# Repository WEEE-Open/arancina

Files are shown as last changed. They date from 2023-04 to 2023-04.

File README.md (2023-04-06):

# Arancina
The **Arancina** (**A**utonomous **R**AM **AN**alysis **CI**rcuit for **N**ot-broken **A**rrays) is a FPGA-based tool for testing the functionality of a DDR RAM, checking its characteristics and operating status through a series of test procedures.

The first prototype is built upon a Terasic [DE0-Nano](https://www.terasic.com.tw/cgi-bin/page/archive.pl?No=593) board, connected to an external DDR memory chip through a custom shield ([DDRacula](pcb/ddracula)), and using an LCD display and a bunch of buttons as user interface.

The tool is still **under heavy development** and not ready for use.

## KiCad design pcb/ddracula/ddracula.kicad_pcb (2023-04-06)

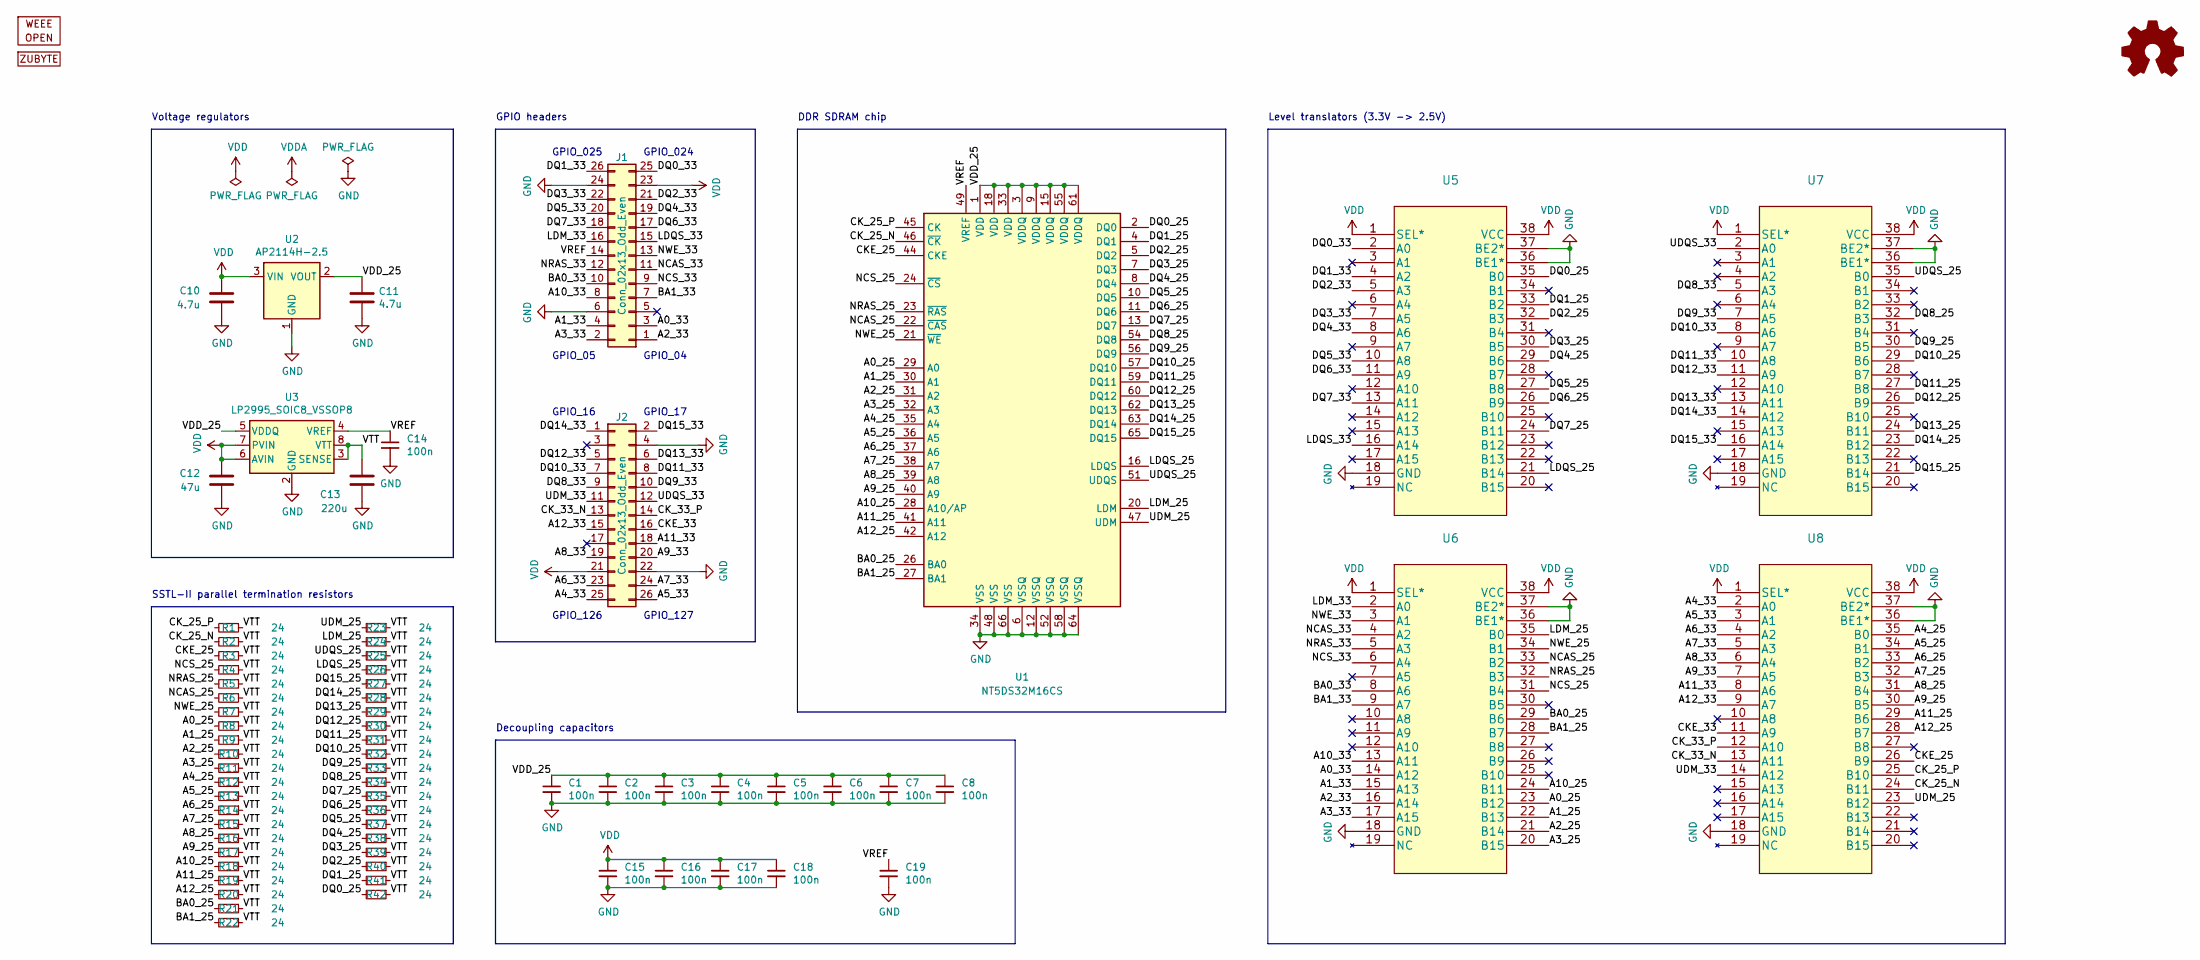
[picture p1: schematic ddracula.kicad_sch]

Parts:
C1, C2, C3, C4, C5, C6, C7, C8, C14, C15, C16, C17, C18, C19: 100n; C_0402_1005Metric
C10, C11: 4.7u; C_0805_2012Metric
C12: 47u; C_0805_2012Metric
C13: 220u; C_1206_3216Metric
J1, J2: Conn_02x13_Odd_Even; PinSocket_2x13_P2.54mm_Vertical
LOGO1: WEEE_Open; Logo_WO_First_Letter
LOGO2: Zubyte; Logo_Zubyte
LOGO3: Logo_Open_Hardware_Small; OSHW-Logo_5.7x6mm_SilkScreen
R1, R2, R3, R4, R5, R6, R7, R8, R9, R10, R11, R12, R13, R14, R15, R16, R17, R18, R19, R20, R21, R22, R23, R24, R25, R26, R27, R28, R29, R30, R31, R32, R33, R34, R35, R36, R37, R38, R39, R40, R41, R42: 24; R_0402_1005Metric
U1: NT5DS32M16CS; TSOP-II-66_22.2x10.16mm_P0.8mm
U2: AP2114H-2.5; SOT-223
U3: LP2995_SOIC8_VSSOP8; SOIC-8_3.9x4.9mm_P1.27mm
U5, U6, U7, U8: (no value)

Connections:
/A0_25: R8.2, U1.29 (A0), U6.23 (B12)
/A0_33: J1.3, U6.14 (A12)
/A1_25: R9.2, U1.30 (A1), U6.22 (B13)
/A1_33: J1.4, U6.15 (A13)
/A2_25: R10.2, U1.31 (A2), U6.21 (B14)
/A2_33: J1.1, U6.16 (A14)
/A3_25: R11.2, U1.32 (A3), U6.20 (B15)
/A3_33: J1.2, U6.17 (A15)
/A4_25: R12.2, U1.35 (A4), U8.35 (B0)
/A4_33: J2.25, U8.2 (A0)
/A5_25: R13.2, U1.36 (A5), U8.34 (B1)
/A5_33: J2.26, U8.3 (A1)
/A6_25: R14.2, U1.37 (A6), U8.33 (B2)
/A6_33: J2.23, U8.4 (A2)
/A7_25: R15.2, U1.38 (A7), U8.32 (B3)
/A7_33: J2.24, U8.5 (A3)
/A8_25: R16.2, U1.39 (A8), U8.31 (B4)
/A8_33: J2.19, U8.6 (A4)
/A9_25: R17.2, U1.40 (A9), U8.30 (B5)
/A9_33: J2.20, U8.7 (A5)
/A10_25: R18.2, U1.28 (A10/AP), U6.24 (B11)
/A10_33: J1.8, U6.13 (A11)
/A11_25: R19.2, U1.41 (A11), U8.29 (B6)
/A11_33: J2.18, U8.8 (A6)
/A12_25: R20.2, U1.42 (A12), U8.28 (B7)
/A12_33: J2.15, U8.9 (A7)
/BA0_25: R21.2, U1.26 (BA0), U6.29 (B6)
/BA0_33: J1.10, U6.8 (A6)
/BA1_25: R22.2, U1.27 (BA1), U6.28 (B7)
/BA1_33: J1.7, U6.9 (A7)
/CKE_25: R3.2, U1.44 (CKE), U8.26 (B9)
/CKE_33: J2.16, U8.11 (A9)
/CK_25_N: R2.2, U1.46 (~CK), U8.24 (B11)
/CK_25_P: R1.2, U1.45 (CK), U8.25 (B10)
/CK_33_N: J2.13, U8.13 (A11)
/CK_33_P: J2.14, U8.12 (A10)
/DQ0_25: R42.2, U1.2 (DQ0), U5.35 (B0)
/DQ0_33: J1.25, U5.2 (A0)
/DQ1_25: R41.2, U1.4 (DQ1), U5.33 (B2)
/DQ1_33: J1.26, U5.4 (A2)
/DQ2_25: R40.2, U1.5 (DQ2), U5.32 (B3)
/DQ2_33: J1.21, U5.5 (A3)
/DQ3_25: R39.2, U1.7 (DQ3), U5.30 (B5)
/DQ3_33: J1.22, U5.7 (A5)
/DQ4_25: R38.2, U1.8 (DQ4), U5.29 (B6)
/DQ4_33: J1.19, U5.8 (A6)
/DQ5_25: R37.2, U1.10 (DQ5), U5.27 (B8)
/DQ5_33: J1.20, U5.10 (A8)
/DQ6_25: R36.2, U1.11 (DQ6), U5.26 (B9)
/DQ6_33: J1.17, U5.11 (A9)
/DQ7_25: R35.2, U1.13 (DQ7), U5.24 (B11)
/DQ7_33: J1.18, U5.13 (A11)
/DQ8_25: R34.2, U1.54 (DQ8), U7.32 (B3)
/DQ8_33: J2.9, U7.5 (A3)
/DQ9_25: R33.2, U1.56 (DQ9), U7.30 (B5)
/DQ9_33: J2.10, U7.7 (A5)
/DQ10_25: R32.2, U1.57 (DQ10), U7.29 (B6)
/DQ10_33: J2.7, U7.8 (A6)
/DQ11_25: R31.2, U1.59 (DQ11), U7.27 (B8)
/DQ11_33: J2.8, U7.10 (A8)
/DQ12_25: R30.2, U1.60 (DQ12), U7.26 (B9)
/DQ12_33: J2.5, U7.11 (A9)
/DQ13_25: R29.2, U1.62 (DQ13), U7.24 (B11)
/DQ13_33: J2.6, U7.13 (A11)
/DQ14_25: R28.2, U1.63 (DQ14), U7.23 (B12)
/DQ14_33: J2.1, U7.14 (A12)
/DQ15_25: R27.2, U1.65 (DQ15), U7.21 (B14)
/DQ15_33: J2.2, U7.16 (A14)
/LDM_25: R24.2, U1.20 (LDM), U6.35 (B0)
/LDM_33: J1.16, U6.2 (A0)
/LDQS_25: R26.2, U1.16 (LDQS), U5.21 (B14)
/LDQS_33: J1.15, U5.16 (A14)
/NCAS_25: R6.2, U1.22 (~CAS), U6.33 (B2)
/NCAS_33: J1.11, U6.4 (A2)
/NCS_25: R4.2, U1.24 (~CS), U6.31 (B4)
/NCS_33: J1.9, U6.6 (A4)
/NRAS_25: R5.2, U1.23 (~RAS), U6.32 (B3)
/NRAS_33: J1.12, U6.5 (A3)
/NWE_25: R7.2, U1.21 (~WE), U6.34 (B1)
/NWE_33: J1.13, U6.3 (A1)
/UDM_25: R23.2, U1.47 (UDM), U8.23 (B12)
/UDM_33: J2.11, U8.14 (A12)
/UDQS_25: R25.2, U1.51 (UDQS), U7.35 (B0)
/UDQS_33: J2.12, U7.2 (A0)
/VDD_25: C1.1, C2.1, C3.1, C4.1, C5.1, C6.1, C7.1, C8.1, C11.1, U1.1 (VDD), U1.3 (VDDQ), U1.9 (VDDQ), U1.15 (VDDQ), U1.18 (VDD), U1.33 (VDD), U1.55 (VDDQ), U1.61 (VDDQ), U2.2 (VOUT), U2.4 (VOUT), U3.5 (VDDQ)
/VREF: C14.1, C19.1, J1.14, U1.49 (VREF), U3.4 (VREF)
/VTT: C13.2, R1.1, R2.1, R3.1, R4.1, R5.1, R6.1, R7.1, R8.1, R9.1, R10.1, R11.1, R12.1, R13.1, R14.1, R15.1, R16.1, R17.1, R18.1, R19.1, R20.1, R21.1, R22.1, R23.1, R24.1, R25.1, R26.1, R27.1, R28.1, R29.1, R30.1, R31.1, R32.1, R33.1, R34.1, R35.1, R36.1, R37.1, R38.1, R39.1, R40.1, R41.1, R42.1, U3.3 (SENSE), U3.8 (VTT)
GND: C1.2, C2.2, C3.2, C4.2, C5.2, C6.2, C7.2, C8.2, C10.1, C11.2, C12.1, C13.1, C14.2, C15.2, C16.2, C17.2, C18.2, C19.2, J1.6, J1.24, J2.4, J2.22, U1.6 (VSSQ), U1.12 (VSSQ), U1.34 (VSS), U1.48 (VSS), U1.52 (VSSQ), U1.58 (VSSQ), U1.64 (VSSQ), U1.66 (VSS), U2.1 (GND), U3.2 (GND), U5.18 (GND), U5.36 (BE1*), U5.37 (BE2*), U6.18 (GND), U6.36 (BE1*), U6.37 (BE2*), U7.18 (GND), U7.36 (BE1*), U7.37 (BE2*), U8.18 (GND), U8.36 (BE1*), U8.37 (BE2*)
VDD: C10.2, C12.2, C15.1, C16.1, C17.1, C18.1, J1.23, J2.21, U2.3 (VIN), U3.6 (AVIN), U3.7 (PVIN), U5.1 (SEL*), U5.38 (VCC), U6.1 (SEL*), U6.38 (VCC), U7.1 (SEL*), U7.38 (VCC), U8.1 (SEL*), U8.38 (VCC)

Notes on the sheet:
GPIO_04
GPIO_05
Level translators (3.3V -> 2.5V)
SSTL-II parallel termination resistors
GPIO_025
GPIO_126
DDR SDRAM chip
GPIO headers
Voltage regulators
Decoupling capacitors
GPIO_024
GPIO_16
GPIO_17
GPIO_127

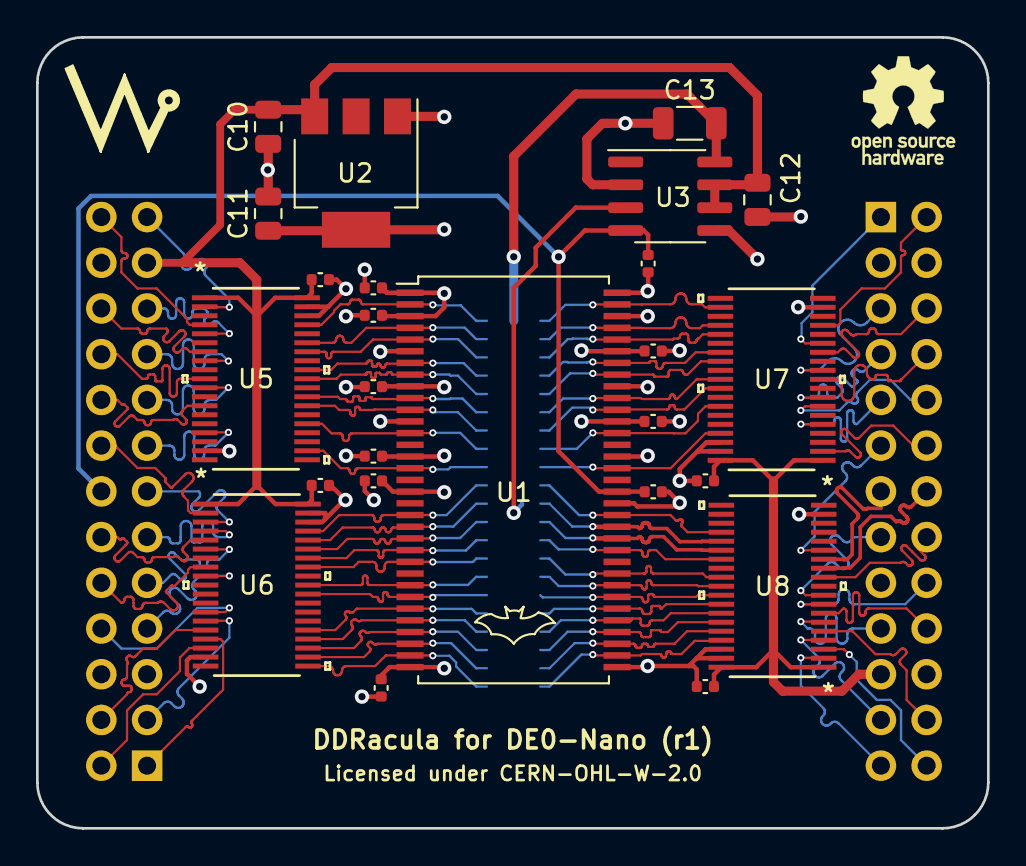
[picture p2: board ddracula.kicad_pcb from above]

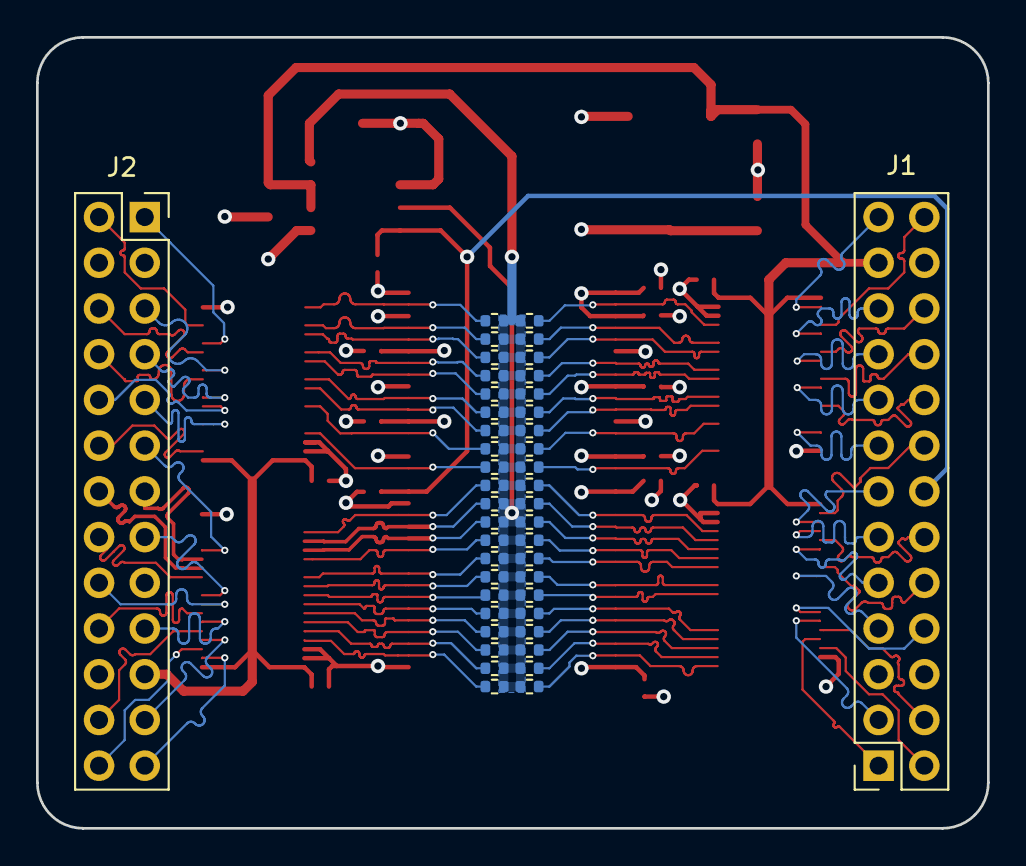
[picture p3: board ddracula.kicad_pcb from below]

Board: 4 copper layers, 52.8 x 43.9 mm, 72 parts (44 on the bottom side), 89 nets.

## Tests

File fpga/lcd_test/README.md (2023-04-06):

# LCD Test Project

A simple project to test the communication between an FPGA and an LCD display connected to its GPIO pins. Includes a fancy progress bar and rotating cursor, for future inclusion in other projects.

### Components:

 - Terasic [DE0-Nano](https://www.terasic.com.tw/cgi-bin/page/archive.pl?No=593) board
 - 20x4 LCD Display (2004A)
 - Contrast regulation potentiometer (10K)

### Software:

 - Quartus Prime Lite Edition 20.1.1
 - ModelSim - Intel FPGA Starter Edition 2020.1

### Screenshot:
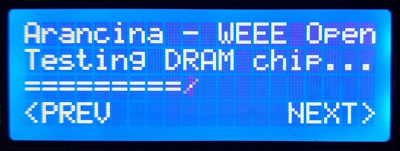
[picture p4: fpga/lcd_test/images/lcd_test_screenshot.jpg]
lcd_test_screenshot


### Data / control signals wiring:
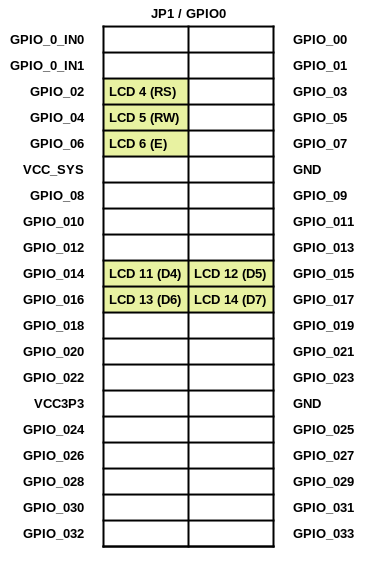
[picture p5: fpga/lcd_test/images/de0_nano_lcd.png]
de0_nano_lcd


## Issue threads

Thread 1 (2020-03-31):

Create Output Module

shishka0, 2020-03-31:
A repeatable module which has to ensure the correct output synchronization *of a single word* to be written in the DDR memory.

This module has to

- Send out the word, its mask and its DQS

- Synchronize the signals

- Use a tri-state buffer for the word and DQS, since their lines are inouts

- Delay DQS of a generic number of system clock cycles (DQS edges are used to sample the word, so the word must be stable before any DQS edge)

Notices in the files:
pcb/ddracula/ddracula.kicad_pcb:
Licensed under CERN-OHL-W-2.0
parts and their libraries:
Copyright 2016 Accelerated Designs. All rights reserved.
